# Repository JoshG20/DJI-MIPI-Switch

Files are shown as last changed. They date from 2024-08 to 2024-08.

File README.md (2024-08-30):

# DJI-MIPI-Switch
2-Camera Input MIPI Switch for Caddx Vista/DJI Air Unit/Runcam Link systems

## V1.0: Initial Revision (INACTIVE)



- The MIPI Switch has 2 MIPI D-PHY CSI inputs and 1 output, all using the DF56C-26P-0.3V(51) connector standard to the 26P DJI FPV system.
- Switching is performed by the PI3WVR646GEEX analog multiplexer, which is the only device in the video signal path.
- Routing is all length and impedence matched within each connector path. The 3 different connectors have different trace lenghts but this does not matter since each camera just sees a slightly longer or shorter total cable length.
- The selection between A and B cameras is controlled by a Pololu RCS01B, which provides a user adjustable PWM threshhold.
- This PCB has 25.5 x 25.5mm mounting holes to match the Caddx Vista and Runcam Link VTX.
- Note1: This board does not pass through the I2C pins, which means cameras that require configuration will not work. Only 60fps cameras are supported.
- Note2: This board is now INACTIVE. Pinout is incorrect.

## V1.1: Fixes V1.0 issues (FUNCTIONAL, SEE NOTE 2)




- Fixed incorrect assumption that the DJI MIPI Coaxial Cable uses a 1-1 pin configuration. This means that pin 1 on the VTX footprint connects to pin 1 on the Camera. In reality, the cable is a 1-n or 1-26 configuration, which flips the pin numbering on one end. VTX-CAM = one flip, so VTX-PCB-CAM needs 3 to match. Therefore V1.1 has mirrored connector pinouts on the camera output connectors, leading to the correct orientation at all stages.
- Improved the silkscreen labeling on the board, including marking the orientation of the PWM input
- Added 20 x 20 mm mounting holes for flexibility
- Note1: Do not use the pinout in this schematic, it has the MIPI lanes in the wrong order and polarity. It does not affect the function of this board, but only because this chip has interchangeable lanes.
- Note2: This board works, however it does have a bug when switching back and forth rapidly (>1Hz). This crashes the VTX until power cycle.

## V2.0: Integrated PWM reading (TBD)

- Size TBD
- Fixed MIPI lane order and polarity on the connectors.
- Replaces 2.54mm pin header with smaller but still common JST SH1.0
- Replaces Pololu RCS01B with integrated PWM reading circuit TBD
- Blocks rapid switching via TBD
- Stretch goal: I2C handling

# Current Pinout Reference:

DJI MIPI Pinout

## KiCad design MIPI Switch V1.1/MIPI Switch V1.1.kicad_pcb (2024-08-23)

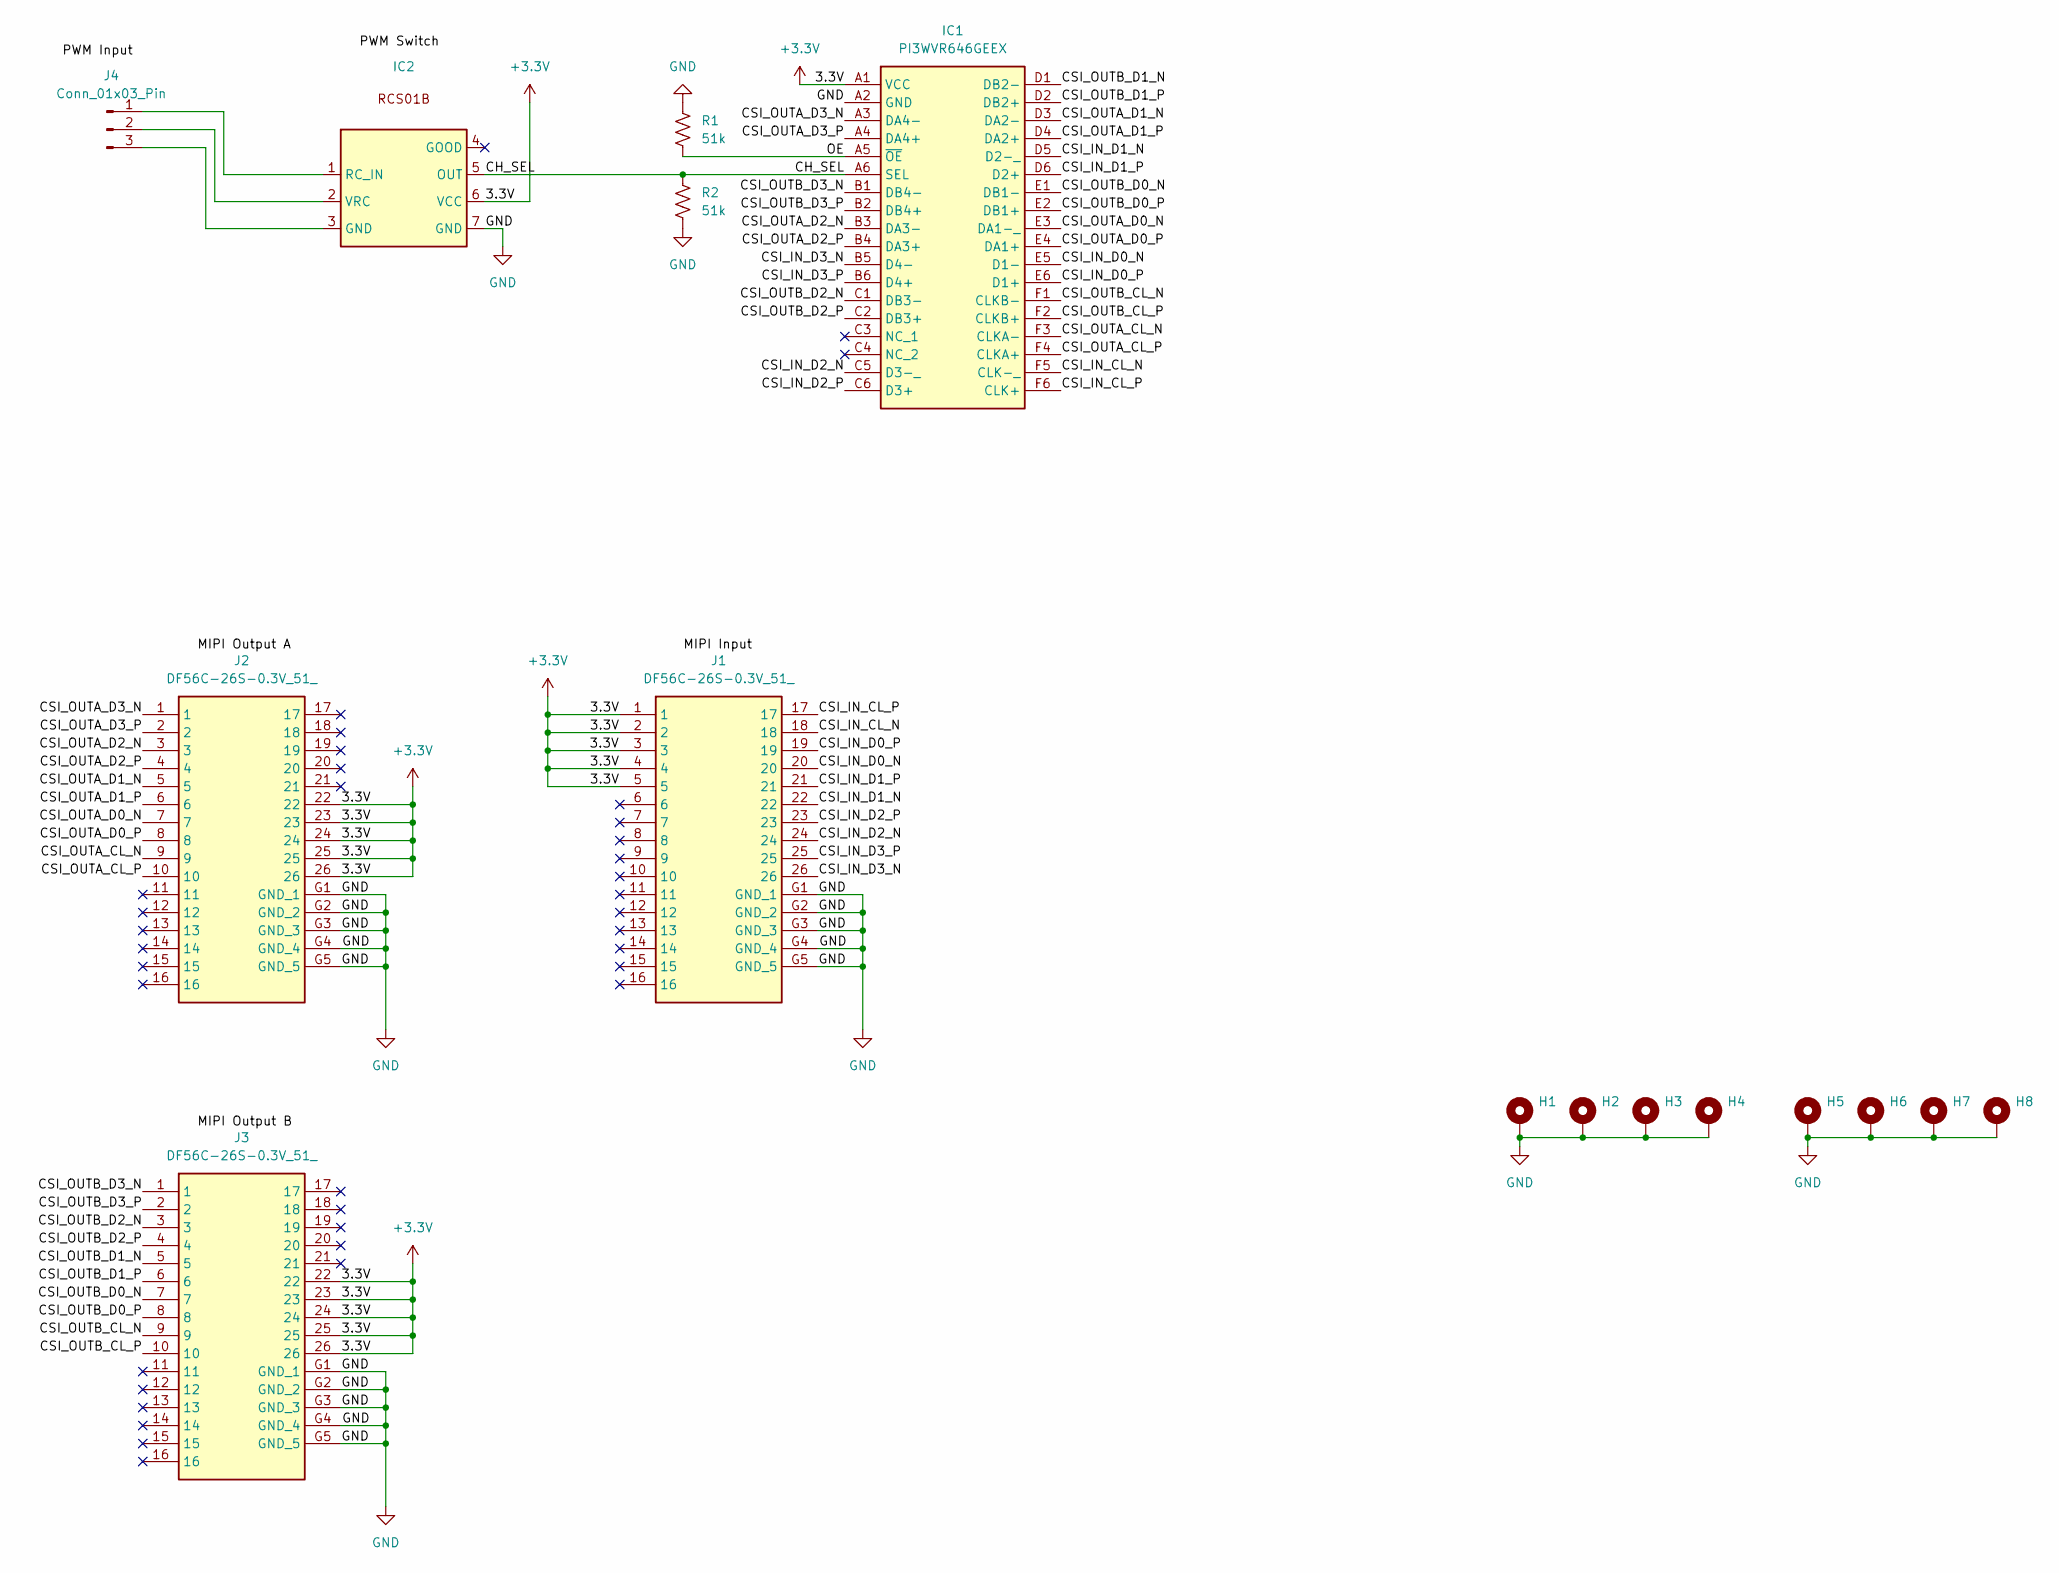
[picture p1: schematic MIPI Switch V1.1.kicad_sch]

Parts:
H1, H2, H3, H4, H5, H6, H7, H8: MountingHole_Pad; MountingHole_2.2mm_M2_Pad
IC1: PI3WVR646GEEX; PI3WVR646GEEX_1; Mouser Part Number 729-PI3WVR646GEEX
IC2: RCS01B_PinHeader_2x04_P2.54mm_Vertical
J1, J2, J3: DF56C-26S-0.3V_51_; DF56C26S03V51; Mouser Part Number 798-DF56C-26S-0.3V51
J4: Conn_01x03_Pin; PinHeader_1x03_P2.54mm_Horizontal
R1, R2: 51k; R_0402_1005Metric

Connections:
+3.3V: IC1.A1 (VCC), IC2.6 (VCC), J1.1, J1.2, J1.3, J1.4, J1.5, J2.22, J2.23, J2.24, J2.25, J2.26, J3.22, J3.23, J3.24, J3.25, J3.26
/CH_SEL: IC1.A6 (SEL), IC2.5 (OUT), R2.1
/CSI_IN_CL_N: IC1.F5 (CLK-_), J1.18
/CSI_IN_CL_P: IC1.F6 (CLK+), J1.17
/CSI_IN_D0_N: IC1.E5 (D1-), J1.20
/CSI_IN_D0_P: IC1.E6 (D1+), J1.19
/CSI_IN_D1_N: IC1.D5 (D2-_), J1.22
/CSI_IN_D1_P: IC1.D6 (D2+), J1.21
/CSI_IN_D2_N: IC1.C5 (D3-_), J1.24
/CSI_IN_D2_P: IC1.C6 (D3+), J1.23
/CSI_IN_D3_N: IC1.B5 (D4-), J1.26
/CSI_IN_D3_P: IC1.B6 (D4+), J1.25
/CSI_OUTA_CL_N: IC1.F3 (CLKA-), J2.9
/CSI_OUTA_CL_P: IC1.F4 (CLKA+), J2.10
/CSI_OUTA_D0_N: IC1.E3 (DA1-_), J2.7
/CSI_OUTA_D0_P: IC1.E4 (DA1+), J2.8
/CSI_OUTA_D1_N: IC1.D3 (DA2-), J2.5
/CSI_OUTA_D1_P: IC1.D4 (DA2+), J2.6
/CSI_OUTA_D2_N: IC1.B3 (DA3-), J2.3
/CSI_OUTA_D2_P: IC1.B4 (DA3+), J2.4
/CSI_OUTA_D3_N: IC1.A3 (DA4-), J2.1
/CSI_OUTA_D3_P: IC1.A4 (DA4+), J2.2
/CSI_OUTB_CL_N: IC1.F1 (CLKB-), J3.9
/CSI_OUTB_CL_P: IC1.F2 (CLKB+), J3.10
/CSI_OUTB_D0_N: IC1.E1 (DB1-), J3.7
/CSI_OUTB_D0_P: IC1.E2 (DB1+), J3.8
/CSI_OUTB_D1_N: IC1.D1 (DB2-), J3.5
/CSI_OUTB_D1_P: IC1.D2 (DB2+), J3.6
/CSI_OUTB_D2_N: IC1.C1 (DB3-), J3.3
/CSI_OUTB_D2_P: IC1.C2 (DB3+), J3.4
/CSI_OUTB_D3_N: IC1.B1 (DB4-), J3.1
/CSI_OUTB_D3_P: IC1.B2 (DB4+), J3.2
/OE: IC1.A5 (~OE), R1.2
GND: H1.1, H2.1, H3.1, H4.1, H5.1, H6.1, H7.1, H8.1, IC1.A2 (GND), IC2.7 (GND), J1.G1 (GND_1), J1.G2 (GND_2), J1.G3 (GND_3), J1.G4 (GND_4), J1.G5 (GND_5), J2.G1 (GND_1), J2.G2 (GND_2), J2.G3 (GND_3), J2.G4 (GND_4), J2.G5 (GND_5), J3.G1 (GND_1), J3.G2 (GND_2), J3.G3 (GND_3), J3.G4 (GND_4), J3.G5 (GND_5), R1.1, R2.2
unnamed: IC2.3 (GND), J4.3
unnamed: IC2.1 (RC_IN), J4.1
unnamed: IC2.2 (VRC), J4.2

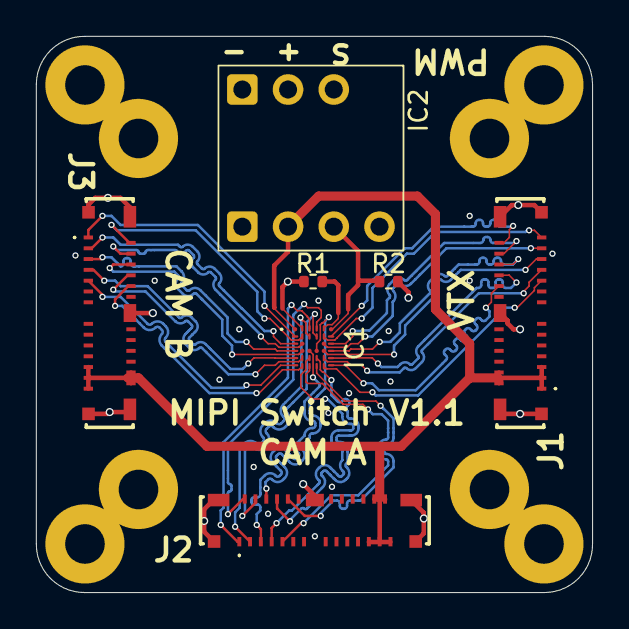
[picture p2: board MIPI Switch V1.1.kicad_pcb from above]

Board: 4 copper layers, 30.9 x 30.9 mm, 15 parts (0 on the bottom side), 34 nets.

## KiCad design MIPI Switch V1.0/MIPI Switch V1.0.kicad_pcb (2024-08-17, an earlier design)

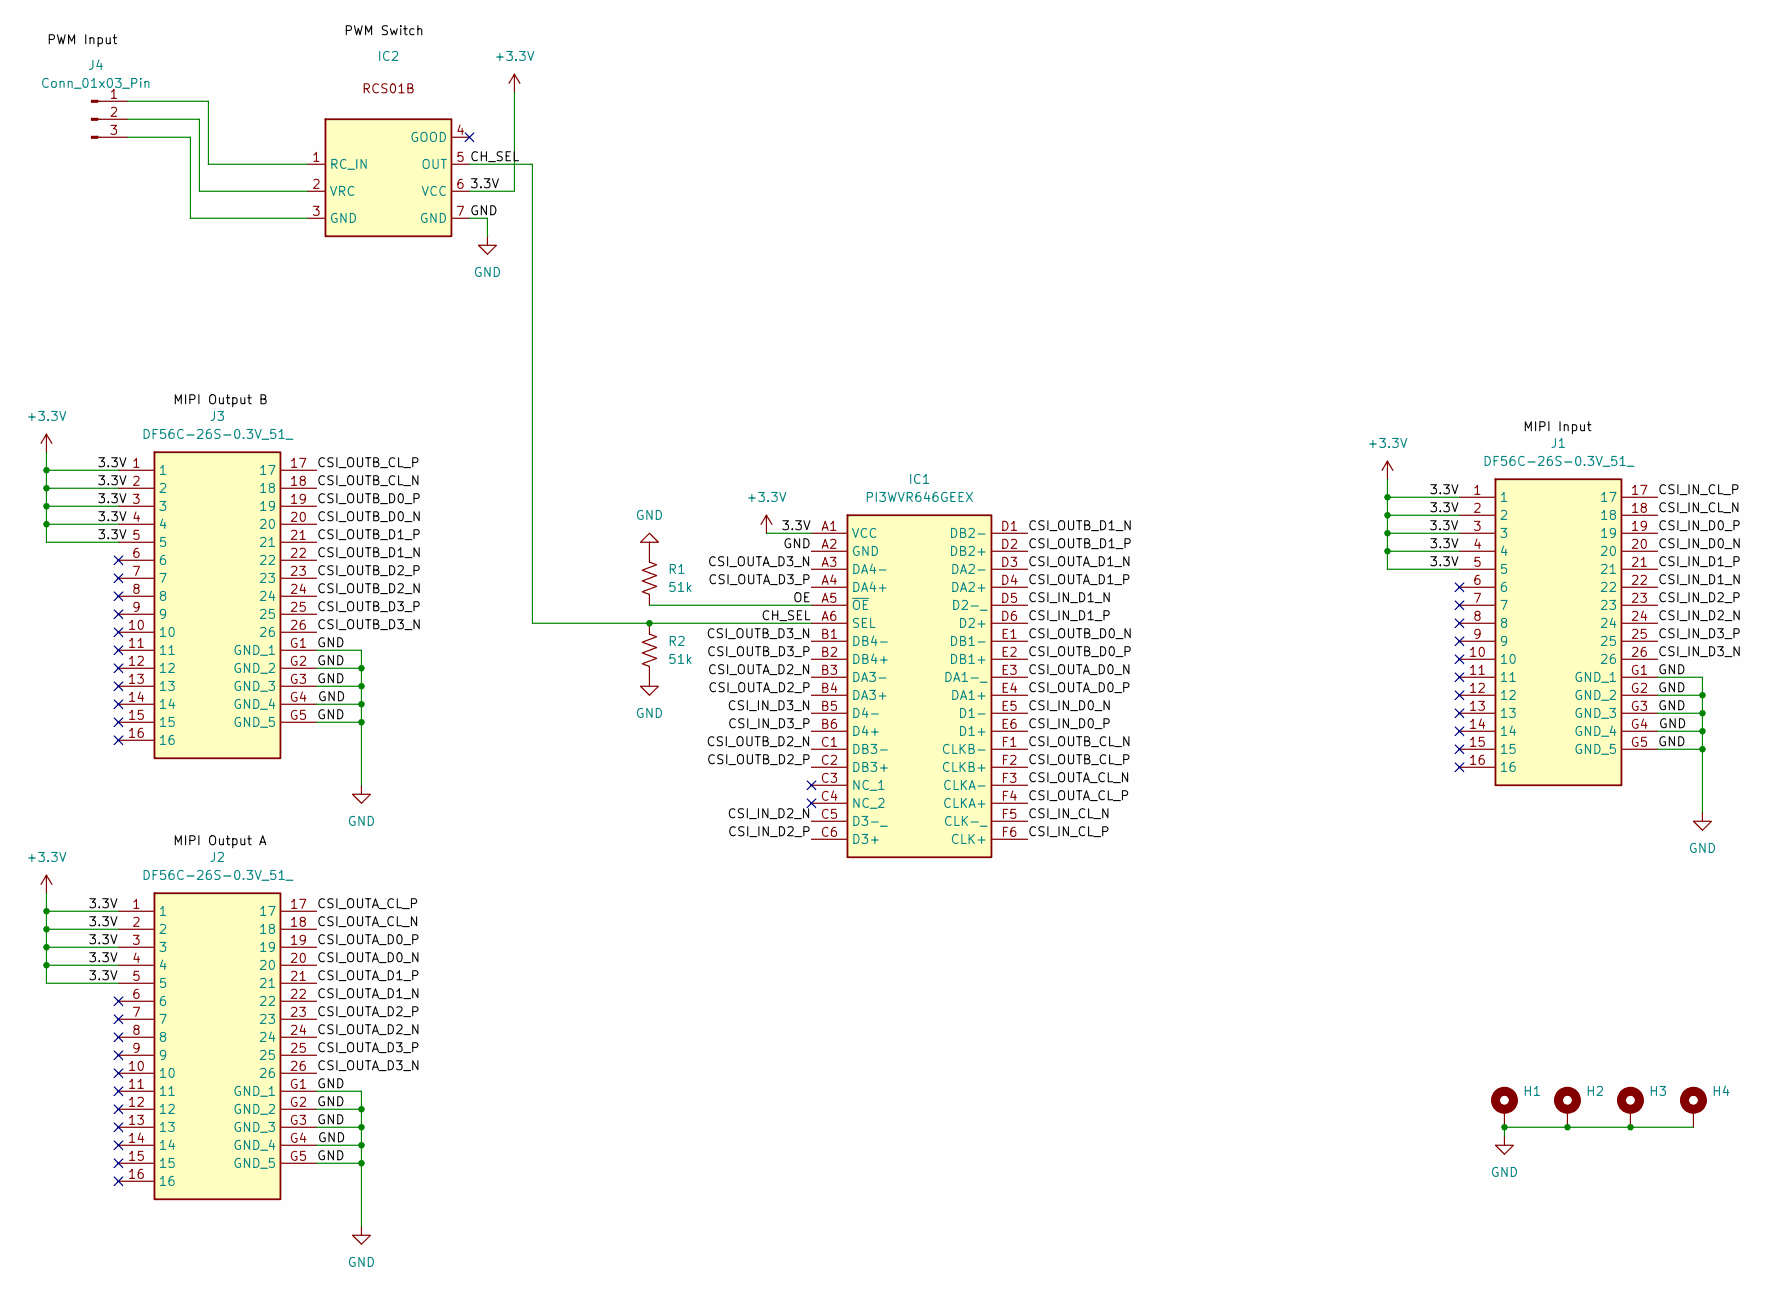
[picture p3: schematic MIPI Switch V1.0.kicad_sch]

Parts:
H1, H2, H3, H4: MountingHole_Pad; MountingHole_2.2mm_M2_Pad
IC1: PI3WVR646GEEX; PI3WVR646GEEX_1; Mouser Part Number 729-PI3WVR646GEEX
IC2: RCS01B_PinHeader_2x04_P2.54mm_Vertical
J1, J2, J3: DF56C-26S-0.3V_51_; DF56C26S03V51; Mouser Part Number 798-DF56C-26S-0.3V51
J4: Conn_01x03_Pin; PinHeader_1x03_P2.54mm_Horizontal
R1, R2: 51k; R_0402_1005Metric

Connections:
+3.3V: IC1.A1 (VCC), IC2.6 (VCC), J1.1, J1.2, J1.3, J1.4, J1.5, J2.1, J2.2, J2.3, J2.4, J2.5, J3.1, J3.2, J3.3, J3.4, J3.5
/CH_SEL: IC1.A6 (SEL), IC2.5 (OUT), R2.1
/CSI_IN_CL_N: IC1.F5 (CLK-_), J1.18
/CSI_IN_CL_P: IC1.F6 (CLK+), J1.17
/CSI_IN_D0_N: IC1.E5 (D1-), J1.20
/CSI_IN_D0_P: IC1.E6 (D1+), J1.19
/CSI_IN_D1_N: IC1.D5 (D2-_), J1.22
/CSI_IN_D1_P: IC1.D6 (D2+), J1.21
/CSI_IN_D2_N: IC1.C5 (D3-_), J1.24
/CSI_IN_D2_P: IC1.C6 (D3+), J1.23
/CSI_IN_D3_N: IC1.B5 (D4-), J1.26
/CSI_IN_D3_P: IC1.B6 (D4+), J1.25
/CSI_OUTA_CL_N: IC1.F3 (CLKA-), J2.18
/CSI_OUTA_CL_P: IC1.F4 (CLKA+), J2.17
/CSI_OUTA_D0_N: IC1.E3 (DA1-_), J2.20
/CSI_OUTA_D0_P: IC1.E4 (DA1+), J2.19
/CSI_OUTA_D1_N: IC1.D3 (DA2-), J2.22
/CSI_OUTA_D1_P: IC1.D4 (DA2+), J2.21
/CSI_OUTA_D2_N: IC1.B3 (DA3-), J2.24
/CSI_OUTA_D2_P: IC1.B4 (DA3+), J2.23
/CSI_OUTA_D3_N: IC1.A3 (DA4-), J2.26
/CSI_OUTA_D3_P: IC1.A4 (DA4+), J2.25
/CSI_OUTB_CL_N: IC1.F1 (CLKB-), J3.18
/CSI_OUTB_CL_P: IC1.F2 (CLKB+), J3.17
/CSI_OUTB_D0_N: IC1.E1 (DB1-), J3.20
/CSI_OUTB_D0_P: IC1.E2 (DB1+), J3.19
/CSI_OUTB_D1_N: IC1.D1 (DB2-), J3.22
/CSI_OUTB_D1_P: IC1.D2 (DB2+), J3.21
/CSI_OUTB_D2_N: IC1.C1 (DB3-), J3.24
/CSI_OUTB_D2_P: IC1.C2 (DB3+), J3.23
/CSI_OUTB_D3_N: IC1.B1 (DB4-), J3.26
/CSI_OUTB_D3_P: IC1.B2 (DB4+), J3.25
/OE: IC1.A5 (~OE), R1.2
GND: H1.1, H2.1, H3.1, H4.1, IC1.A2 (GND), IC2.7 (GND), J1.G1 (GND_1), J1.G2 (GND_2), J1.G3 (GND_3), J1.G4 (GND_4), J1.G5 (GND_5), J2.G1 (GND_1), J2.G2 (GND_2), J2.G3 (GND_3), J2.G4 (GND_4), J2.G5 (GND_5), J3.G1 (GND_1), J3.G2 (GND_2), J3.G3 (GND_3), J3.G4 (GND_4), J3.G5 (GND_5), R1.1, R2.2
unnamed: IC2.3 (GND), J4.3
unnamed: IC2.1 (RC_IN), J4.1
unnamed: IC2.2 (VRC), J4.2

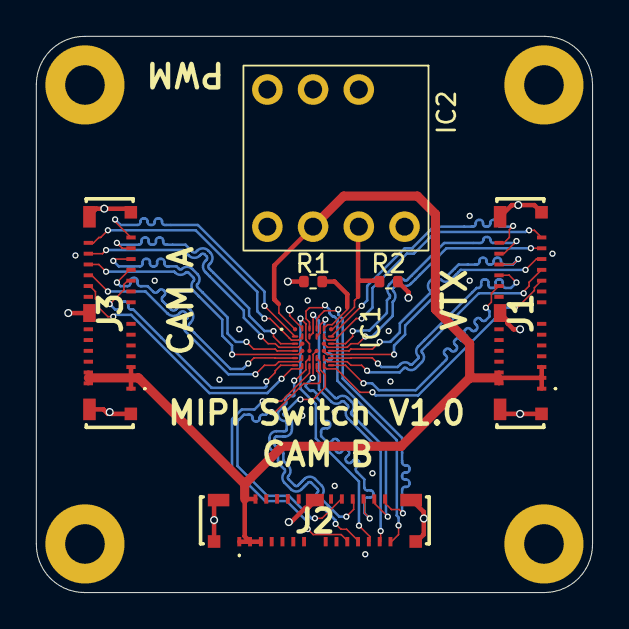
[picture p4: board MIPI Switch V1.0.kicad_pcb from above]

Board: 4 copper layers, 30.9 x 30.9 mm, 11 parts (0 on the bottom side), 34 nets.

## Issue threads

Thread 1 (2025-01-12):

Where to buy?

jeremy-niles, 2025-01-12:
Hi @JoshG20,

Do you have spare board to sell or a PCB vendor that you can recommend for 1-2pc orders in USA?

Cheers,

JN

JoshG20, 2025-01-12:
I do have spares. I can ship you 2 of the V1.1 boards and the pwm switches that go on them at cost.
I will however note that I was unable to solve the risk of crashing the vtx and requiring a power cycle. I now believe the root cause is switching in the middle of a frame, not the speed of switching. Practically, this means that there's a percentage chance it could crash any time you switch if it lands on a frame.
I would not recommend relying on it, but if you wanted it for development I think the cost adds up to $23 each plus $11 USPS shipping. If you want to make your own, I ordered from JLCPCB, min qty 5, total including assembly around $95, plus the 5 $5 RC switches. Earliest I could ship is 1/23, let me know what you want or if you have any questions!

jeremy-niles, 2025-01-14:
My hero! I want to get one. Tell me where to email/pay.

jeremy-niles, 2025-03-16:
Hi @JoshG20 I am still interested! Please let me know if you're still game.

JoshG20, 2025-03-16:
I am, for this you can email me at: joshg20public@gmail.com

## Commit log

2024-08-17 Initial Upload
    [MIPI Switch V1.0.kicad_pcb, MIPI Switch V1.0.kicad_sch, bom.csv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]
2024-08-23 Delete MIPI Switch V1.0/production directory
    cleanup inactive version
    [bom.csv, designators.csv, positions.csv]
2024-08-23 Delete MIPI Switch V1.0/MIPI Switch V1.0-backups directory
    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
2024-08-23 Add V1.1 files
    [MIPI Switch V1.1.kicad_pcb, MIPI Switch V1.1.kicad_sch]
2024-08-23 Update README.md
    added current pinout for reference
